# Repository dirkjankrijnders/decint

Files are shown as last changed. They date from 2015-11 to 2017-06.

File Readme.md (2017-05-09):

Decoder interface
=================

A simple PCB to interface a microcontroller (or any other 5V logic) to either Loconet or track based signals such as DCC/Motorola/MFX/Selectrix. Interface knows nothing about the protocols. Note that the track signal can also come from the railsync lines on Loconet.

The interface can provide full opto-isolation from the track signal and provides 4 open collector opto-isolated feedback ports. Also it has a ACK generator for operating in DCC Service Mode.

The micro controller connection is primarily meant for mounting a Arduino Pro Mini or Pro Micro, but any connection can of course be made.

The board:
----------


The BOM
-------

| Reference | | Value | MFN | MFP | S1PN | S1PL |
|---|---|---|---|---|---|---|
| U102 | 1 | 6N137 | FAIRCHILD SEMICONDUCTOR | 6N137SDM | 2322504 | http://nl.farnell.com/fairchild-semiconductor/6n137sdm/opto-cplr-logic-gate-o-p-5kv-smd/dp/2322504 |
| D101, D102 | 2 | BAV199 | NXP | BAV99W,115 | 1081212 | http://nl.farnell.com/nxp/bav99w-115/diode-dual-0-15a-100v-sot-323/dp/1081212 |
| Q102 | 1 | BC849 | | | | |
| Q101 | 1 | BC857 | | | | |
| C101 | 1 | CAP | | | | |
| D104 | 1 | 1N4148 | | | | |
| D103 | 1 | D_Small | | | | |
| U106 | 1 | LM311N | Texas Instruments | LM311 | | |
| U103 | 1 | LTV-817 | LITEON | LTV-817S-V | | |
| J104, J105 | 2 | RJ12 | Lumberg | P 128 | 1243235 | http://nl.farnell.com/lumberg/p-128/modular-plug-crimp-rj12-6p6c/dp/1243235 |
| R101 | 1 | 100 | | | | |
| R108 | 1 | 10k | | | | |
| R102 | 1 | 1k5 | | | | |
| R103, R104, R105, R106, R107 | 5 | 1k | | | | |
| R109 | 1 | 4k7 | | | | |
| R110 | 1 | 47k | | | | |
| R112 | 1 | 10k | | | | |
| R111 | 1 | 150k | | | | |
| R113 | 1 | 22k | | | | |
| R114 | 1 | 220k | | | | |
| U101 | 1 | OPTO-TRANSISTOR-4 | Vishay | TCMT4100 | 1779650 | http://nl.farnell.com/vishay/tcmt4100/optocplr-smd-16pin-4ch-trans-syst/dp/1779650 |
| U104 | 1 | LM1117 | Texas Instruments |LM1117MP-5.0 | 9778209 | http://nl.farnell.com/texas-instruments/lm1117mp-5-0/ldo-0-8a-5v-sot-223/dp/9778209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 |

Note: The LM311 footprint on the PCB is meant for a DIP8-smd package, which doesn't really exist, bending the leads flat and soldering will work, in Rev.2 this will be a SOIC8 footprint.

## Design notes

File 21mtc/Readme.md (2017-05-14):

This is a simple board to mount in a locomotive for interfacing to decoder. It supports both the 8-pin header connector (NMRA S-9.1.1, Medium connector) and the NEM660 version of the MTC21 connector, altough it is perfectly usable as a NMRA version, just the silkscreen is incorrect.

BOM
---

| Designator | value | supplier | spl. no. | Description |
|---|---|---|---|---|
| P102 | | | | 0.05" pitch, 22 pin, SMD male header |
| R101, R104 | | | | 1k, 0805 SMD Resistor |
| R102, R103 | | | | 1k, 0805 SMD Resistor |
| Q101 | FDC6303N  | Farnell  | [1467964](http://nl.farnell.com/fairchild-semiconductor/fdc6303n/mosfet-dual-n-smd-supersot-6/dp/1467964)  | FAIRCHILD SEMICONDUCTOR  FDC6303N  Dual MOSFET, Dual N Channel, 680 mA, 25 V, 450 mohm, 4.5 V, 800 mV |
| R105 | | | | 100 Ohm, 0805 SMD Resistor |
| D101 | S1G | Farnell  | [2675039](http://nl.farnell.com/multicomp/s1g/rectifier-single-1a-400v-do-214ac/dp/2675039) | S1G, 1.0A SMD Diode |

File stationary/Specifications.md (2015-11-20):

Specification Decoder interface
===============================

Sources of signal
-----------------

- Railsync on loconet connector (isolated)
- Loconet
- Track (isolated)

Sources of power
----------------
Linear power regulator
- External
- Track (Only with track as signal source)

Feedback
--------
All Isolated

- Ack generator
- 4 feedback ports

ISP
---
On decoder board itself, or via Arduino bootloader (USB/FTDI).

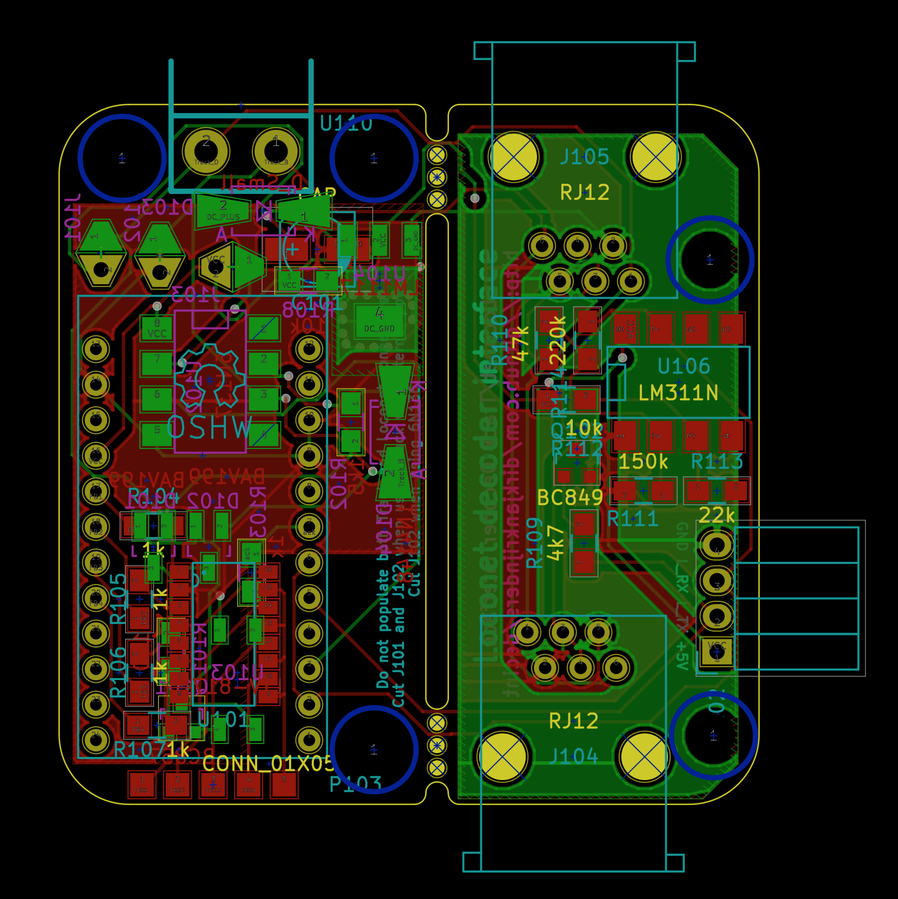
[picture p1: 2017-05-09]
Media/PCB.png

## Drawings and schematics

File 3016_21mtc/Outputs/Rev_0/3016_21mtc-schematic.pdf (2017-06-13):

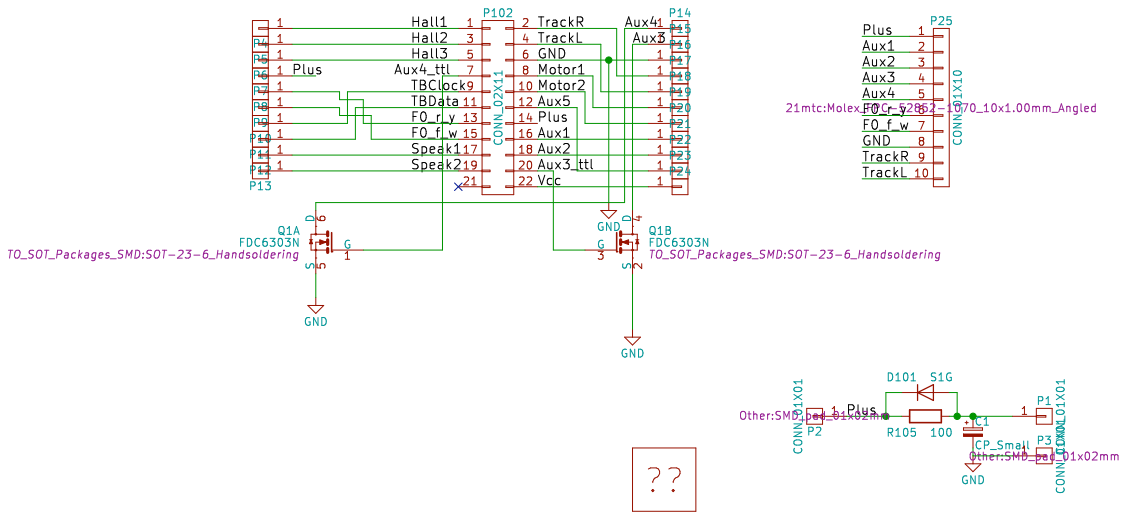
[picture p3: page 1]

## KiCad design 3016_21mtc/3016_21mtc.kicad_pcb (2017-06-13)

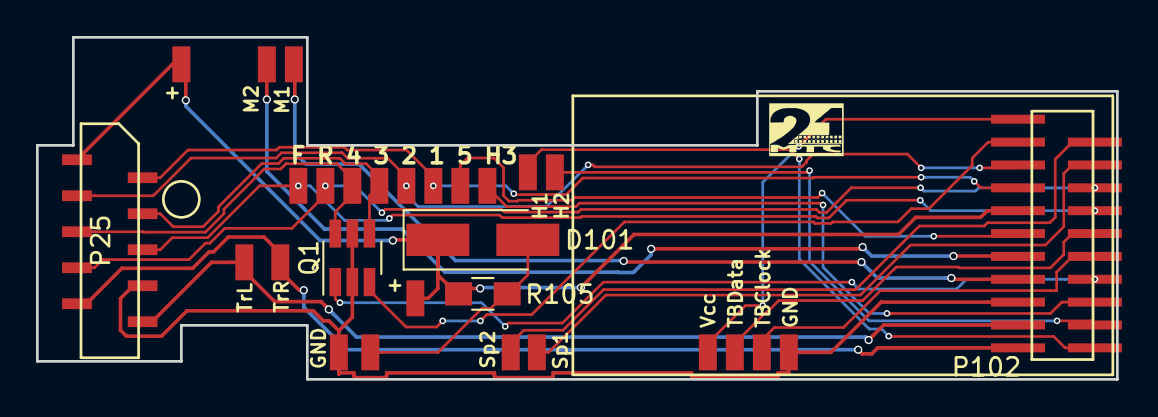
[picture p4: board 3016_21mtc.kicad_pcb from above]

Board: 2 copper layers, 60.0 x 19.0 mm, 29 parts (0 on the bottom side), 24 nets.

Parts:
D101: S1G; D_SMA_Handsoldering
P1, P2, P3, P4, P5, P6, P7, P8, P9, P10, P11, P12, P13, P14, P15, P16, P17, P18, P19, P20, P21, P22, P23, P24: CONN_01X01; SMD_pad_01x02mm
P25: CONN_01X10; Molex_FPC-52808-1071_vertical
P102: CONN_02X11; Pin_Header_Straight_2x11_1.27_smd
Q1: FDC6303N; SOT-23-6_Handsoldering
R105: 100; R_0805_HandSoldering

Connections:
/Aux1: P21.1, P25.2, P102.16
/Aux2: P22.1, P25.3, P102.18
/Aux3: P15.1, P25.4, Q1.4
/Aux3_ttl: P102.20, Q1.3
/Aux4: P14.1, P25.5, Q1.6
/Aux4_ttl: P102.7, Q1.1
/Aux5: P23.1, P102.12
/F0_f_w: P9.1, P25.7, P102.15
/F0_r_y: P8.1, P25.6, P102.13
/Hall1: P4.1, P102.1
/Hall2: P5.1, P102.3
/Hall3: P6.1, P102.5
/Motor1: P19.1, P102.8
/Motor2: P20.1, P102.10
/Plus: D101.1, P2.1, P7.1, P25.1, P102.14, R105.2
/Speak1: P12.1, P102.17
/Speak2: P13.1, P102.19
/TBClock: P10.1, P102.9
/TBData: P11.1, P102.11
/TrackL: P18.1, P25.10, P102.4
/TrackR: P17.1, P25.9, P102.2
/Vcc: P24.1, P102.22
GND: P3.1, P16.1, P25.8, P102.6, Q1.2, Q1.5
unnamed: D101.2, P1.1, R105.1

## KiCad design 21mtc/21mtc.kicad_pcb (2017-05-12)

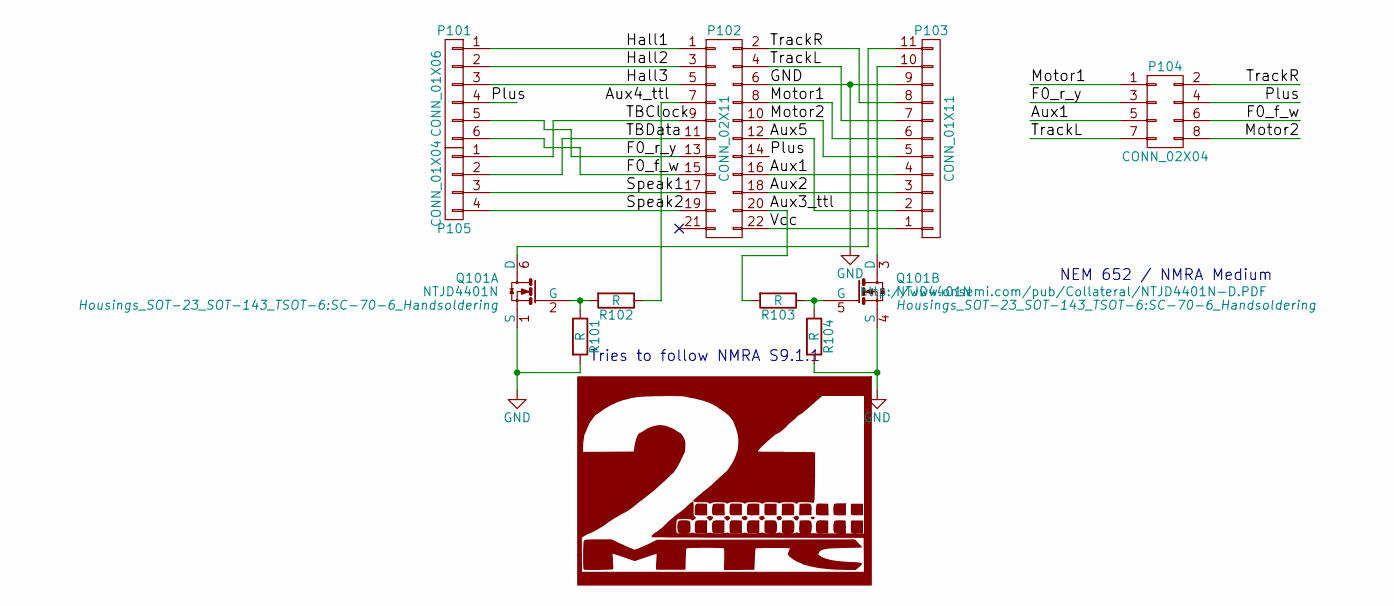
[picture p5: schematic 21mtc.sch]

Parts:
P101: CONN_01X06; solderpads_1x06_2mm
P102: CONN_02X11; Pin_Header_Straight_2x11_1.27_smd
P103: CONN_01X11; solderpads_1x11_2mm
P104: CONN_02X04; Pin_Header_Straight_2x04
P105: CONN_01X04; solderpads_1x04_2mm
Q101: NTJD4401N; SC-70-6_Handsoldering
R101, R102, R103, R104: R; R_0805_HandSoldering

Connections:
/Aux1: P102.16, P103.4, P104.5
/Aux2: P102.18, P103.3
/Aux3_ttl: P102.20, R103.2
/Aux4_ttl: P102.7, R102.1
/Aux5: P102.12, P103.2
/F0_f_w: P101.6, P102.15, P104.6
/F0_r_y: P101.5, P102.13, P104.3
/Hall1: P101.1, P102.1
/Hall2: P101.2, P102.3
/Hall3: P101.3, P102.5
/Motor1: P102.8, P103.6, P104.1
/Motor2: P102.10, P103.5, P104.8
/Plus: P101.4, P102.14, P104.4
/Speak1: P102.17, P105.3
/Speak2: P102.19, P105.4
/TBClock: P102.9, P105.1
/TBData: P102.11, P105.2
/TrackL: P102.4, P103.7, P104.7
/TrackR: P102.2, P103.8, P104.2
/Vcc: P102.22, P103.1
unnamed: P103.10, Q101.3 (D)
unnamed: Q101.2 (G), R101.1, R102.2
unnamed: Q101.5 (G), R103.1, R104.1

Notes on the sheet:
Tries to follow NMRA S9.1.1
NEM 652 / NMRA Medium

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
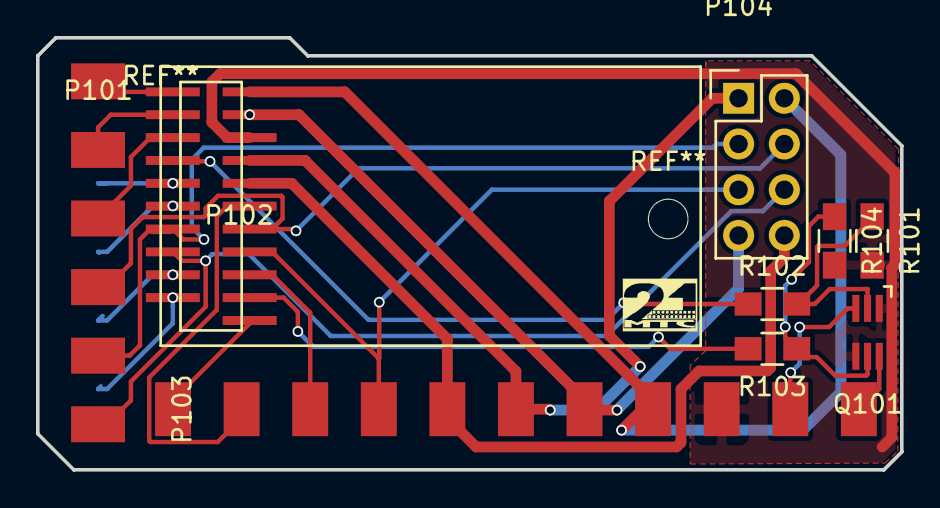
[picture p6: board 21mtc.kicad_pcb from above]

Board: 2 copper layers, 48.0 x 24.0 mm, 10 parts (1 on the bottom side), 25 nets.

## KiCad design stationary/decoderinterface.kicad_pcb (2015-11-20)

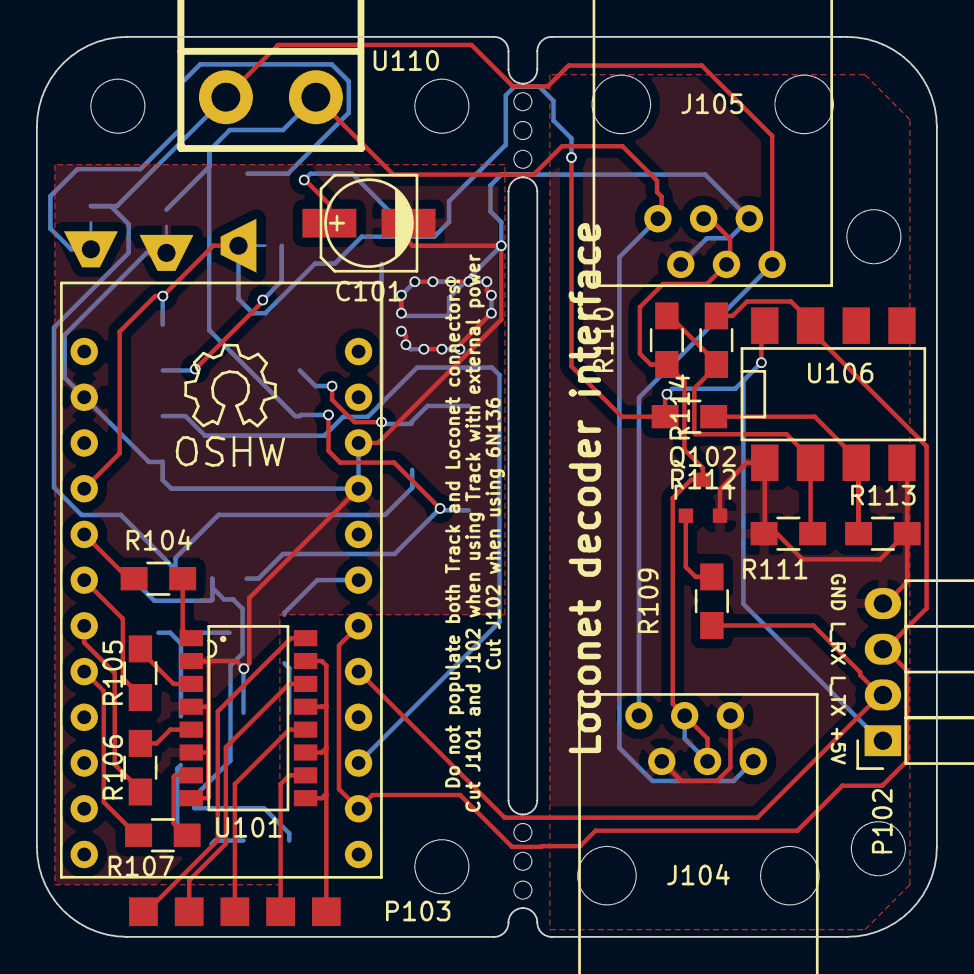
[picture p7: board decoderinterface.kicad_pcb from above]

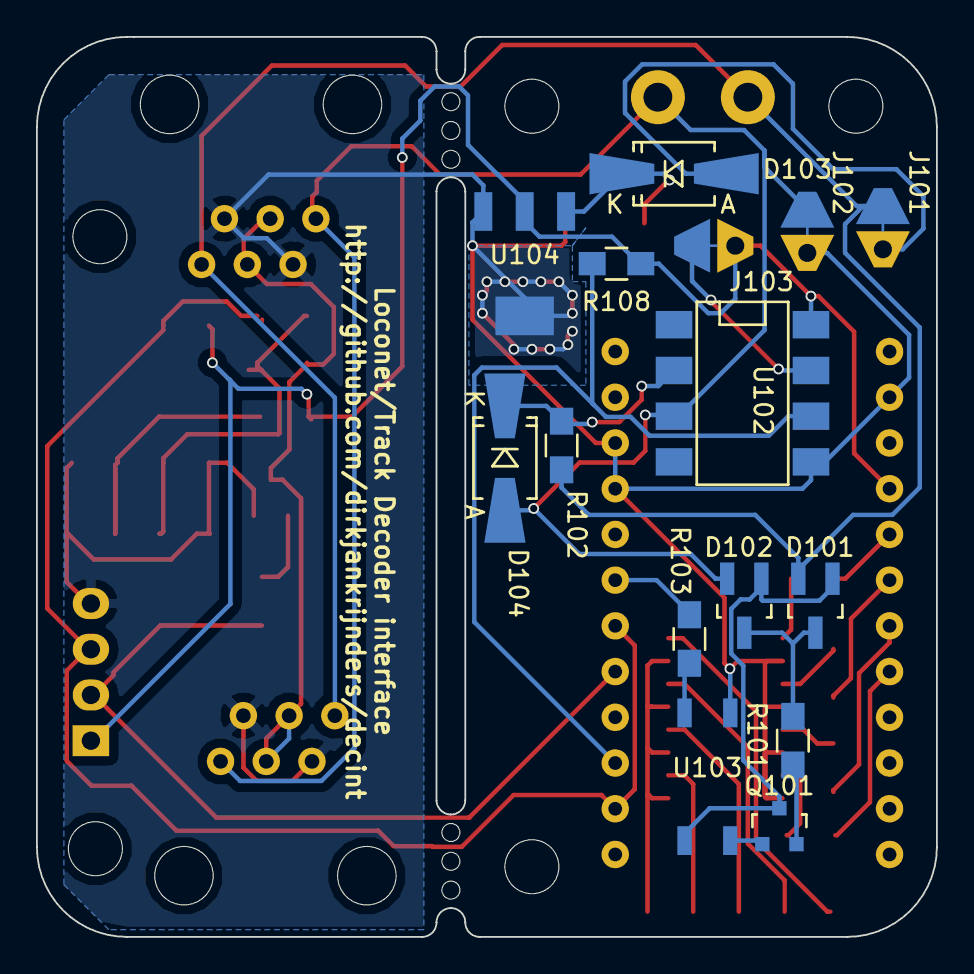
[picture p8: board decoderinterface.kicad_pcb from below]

Board: 2 copper layers, 50.0 x 50.0 mm, 39 parts (15 on the bottom side), 34 nets.

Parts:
C101: CAP; c_elec_5x4.5
D101, D102: BAV199; SOT-23_Handsoldering
D103: D_Small; Diode-Universal-SMA-SMB_Handsoldering
D104: 1N4148; Diode-Universal-SMA-SMB_Handsoldering
J101, J102, J103: SOLDER_JUMPER_CONN; solder_jumper_conn
J104, J105: RJ12; RJ12_horizontal
P101: CONN_01X02; 2PIN_Screw_Block
P102: CONN_01X04; Socket_Strip_Angled_1x04
P103: CONN_01X05; SMD_PIN_01x05
Q101: BC857; SOT-23
Q102: BC849; SOT-23
R101: 100; R_0805_HandSoldering
R102: 1k5; R_0805_HandSoldering
R103, R104, R105, R106, R107: 1k; R_0805_HandSoldering
R108, R112: 10k; R_0805_HandSoldering
R109: 4k7; R_0805_HandSoldering
R110: 47k; R_0805_HandSoldering
R111: 150k; R_0805_HandSoldering
R113: 22k; R_0805_HandSoldering
R114: 220k; R_0805_HandSoldering
U101: OPTO-TRANSISTOR-4; HalfPitchMiniFlatPackage
U102: 6N137; DIP-8_SMD
U103: LTV-817; LTV_354
U104: LM1117; SOT-223
U105: Arduino_Pro_Micro
U106: LM311N; DIP-8_SMD
U107, U108, U109, U110: M3_Mounting_hole; MountingHole_3mm

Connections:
DC_GND: C101.2, J102.2, J104.2, J104.5, J105.2, J105.5, P102.4, Q102.2, R111.2, R113.2, U101.2, U101.4, U101.6, U101.8, U102.5, U103.1, U104.3, U104.4, U105.9, U105.10, U105.14, U106.1, U106.4
DC_PLUS: D103.2, J101.2
FB1: R104.1, U105.17
FB2: R105.1, U105.18
FB3: R106.1, U105.19
FB4: R107.1, U105.20
FBO1: P103.1, U101.16
FBO2: P103.2, U101.14
FBO3: P103.3, U101.12
FBO4: P103.4, U101.10
FBO_COMMON: P103.5, U101.9, U101.11, U101.13, U101.15
Loconet: J104.3, J104.4, J105.3, J105.4, Q102.3, R110.1
Loconet_RX: P102.3, R114.1, U105.2, U105.6, U106.7
Loconet_TX: P102.2, R109.1, U105.5
unnamed: C101.1, D103.1, U104.1
unnamed: D101.1, D102.1, Q101.3, U103.3
unnamed: D101.3, D102.3, R101.2
unnamed: D104.1, R102.1, U102.2
unnamed: J103.1, U102.7
unnamed: Q101.1, U103.4
unnamed: Q101.2, R101.1
unnamed: Q102.1, R109.2
unnamed: R103.2, U103.2
unnamed: R104.2, U101.1
unnamed: R105.2, U101.3
unnamed: R106.2, U101.5
unnamed: R107.2, U101.7
unnamed: R110.2, R111.1, R114.2, U106.2
unnamed: R112.2, R113.1, U106.3
Track_B: D102.2, D104.2, J102.1, J104.6, J105.6, P101.1, U102.3
Track_O: D101.2, J101.1, J104.1, J105.1, P101.2, R102.2
VCC: J103.2, P102.1, R108.1, R112.1, U102.8, U104.2, U105.16, U106.8
ack: R103.1, U105.7
tracksignal: R108.2, U102.6, U105.3

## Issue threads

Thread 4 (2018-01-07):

Fix LM1117 footprint

dirkjankrijnders, 2018-01-07:

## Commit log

2015-11-20 First revision
    [decoderinterface-B_Cu.gbl, decoderinterface-B_Fab.gbr, decoderinterface-B_Mask.gbs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]
2015-11-20 added BOM
2015-11-20 Small update on BOM
2015-11-21 Better BOM
2015-11-21 Improved BOM information
    [decoderinterface.sch]
2015-11-21 Small BOM information improvement
    [decoderinterface.sch]
2015-11-22 Fix the RJ12 footprint in de BOM data
    [decoderinterface.sch]
2015-12-14 Restructure directories
    [decoderinterface-B_Cu.gbl, decoderinterface-B_Fab.gbr, decoderinterface-B_Mask.gbs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]
2015-12-14 Start 21MTC / NEM 652 system board
    [21mtc.kicad_pcb, 21mtc.sch]
2015-12-15 Layout of a first draft
    [21mtc.kicad_pcb, 21mtc.sch]
2016-05-01 MTC21 Updates
    [21mtc.kicad_pcb, 21mtc.sch]
2017-05-09 Silkscreen and track width fixes
    [21mtc.kicad_pcb]
2017-05-09 Made the design rule for power nets, track width 0.6mm
    [21mtc.kicad_pcb]
2017-05-12 Put the F0 pads on the front, moved the TB* pads to the back
    [21mtc.sch]
2017-05-12 Library management
    [21mtc.kicad_pcb, 21mtc.sch]
2017-06-13 First revision of 3016 board
    [3016_21mtc.kicad_pcb, 3016_21mtc.sch]
2017-06-13 Added gerbers
    [3016_21mtc-B.Cu.gbr, 3016_21mtc-B.Mask.gbr, 3016_21mtc-B.SilkS.gbr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]
2017-06-13 Added schematic and 3D render
2017-06-13 Switched to Protel gerber naming
    [016_21mtc-Edge.Cuts.gm1, 3016_21mtc-B.Cu.gbl, 3016_21mtc-B.Mask.gbs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]
2018-03-22 Fixed LM311 footprint and LM1117 symbol
    [decoderinterface.sch]
